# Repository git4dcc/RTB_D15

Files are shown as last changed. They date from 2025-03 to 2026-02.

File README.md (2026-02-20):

# RTB_D15




My Homebrew [D15](https://rtb4dcc.de/hardware/decoder/d15/) decoder is a drop in replacement for the original analog Minitrix (#11130) PCB. The decoder is designed to integrate into the [RTB](https://rtb4dcc.de/concept/) digital control infrastructure.

<details>
<summary>See also</summary>

- [RTB_D12 - custom](/../../../../git4dcc/RTB_D12) (Fleischmann V100)
- [RTB_D13 - custom](/../../../../git4dcc/RTB_D13) (Minitrix coach)
- [RTB_D16 - NEM651](/../../../../git4dcc/RTB_D16)
- [RTB_D20 - NEM651](/../../../../git4dcc/RTB_D20)
- [RTB_D21 - Next18](/../../../../git4dcc/RTB_D21)
- [RTB_D22 - Plux16](/../../../../git4dcc/RTB_D22)
- [RTB_D23 - NEM652](/../../../../git4dcc/RTB_D23)

</details>

<details>
<summary>User Guides</summary>

- User Guide - DE
- [User Guide - EN](https://rtb4dcc.de/rtb_decoder_reference_en/)

</details>

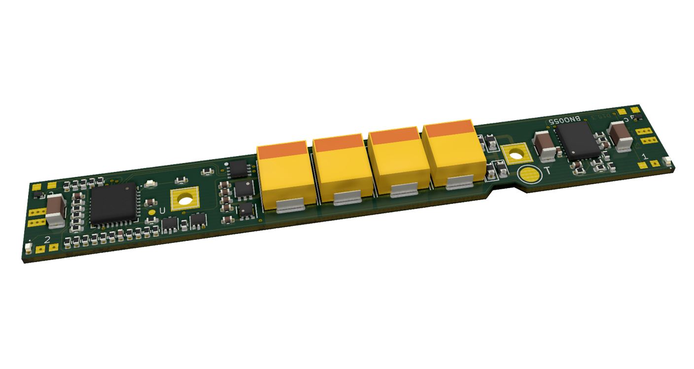
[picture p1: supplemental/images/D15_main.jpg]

<br>

## Decoder features
- **Minitirx V160** PCB decoder
- **DCC**
  - DCC-A automatic logon
  - DCC-R protocol extension
  - Service Mode Programming
- **Railcom**
  - Channel 1/2
  - POM, xPOM
  - DYN: Speed, QoS, Track-voltage, Motor-current, AUX-current, Temp, Distance travelled
- 7-18V track voltage
- heartbeat LED
- adjustable max motor current (default 250mA)
- adjustable max AUX current (default 250mA)
- over temp protection
- Function output: LF/LR (dimmable, 1.4kHz), LED on PCB
- Function output: AUX1/AUX2 (dimmable, 1.4kHz) for driver cabin (LEDs on PCB)
- Function output: AUX3/AUX4 logic level
- Function output: AUX5/AUX6 open drain (each 250mA)
- buffer capacitor 4x330uF
- optional 9-axis orientation sensor
- <10mA idle power consumption
- Firmware update over main tracks via DCC-R protocol

# Hardware
The current PCB layout uses SMD footprints with 0.5mm pitch and mainly 0402 parts. Reflow soldering is mandatory whereas handsoldering almost impossible.

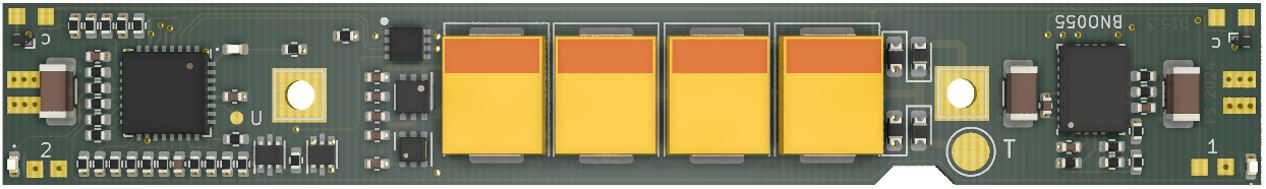
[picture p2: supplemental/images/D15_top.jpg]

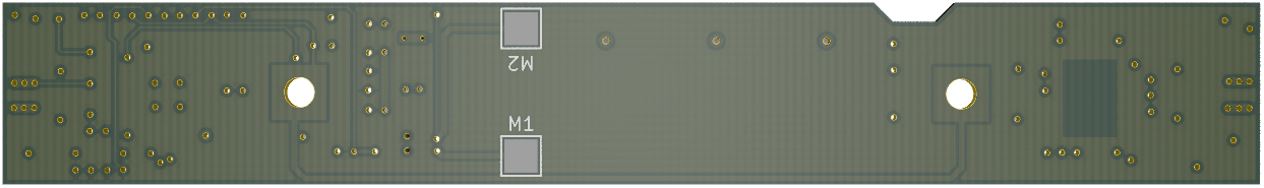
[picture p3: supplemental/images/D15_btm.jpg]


## PCB
- 4-layer PCB, FR4, 0.8mm
- CPU: AVR64DA32
- Motor bridge: DRV8231
- Inrush limiter: TPS22810
- 9-axis absolute-orientation sensor: BNO055

## Kicad
[Schematic](doc/D12_schematic.pdf) | [Layout](doc/D12_layout.pdf) | [Gerber](gerber)

<details>
<summary>Dependency</summary>
<br>

:yellow_circle: Requires my Kicad project library [RTB_SamacSys](https://github.com/git4dcc/RTB_SamacSys) in the same directory tree.

</details>

## Firmware
Filename structure: { **pcb** }{ **code** }{ **version** }.hex

Example: **D15F0001**.hex

| | Description |
| --- | --- |
| **pcb** | Name of matching hardware (**D12**) |
| **code** | Type of code contained (**R**=rom, **B**=bootloader, **F**=flash, **U**=bld update, **P**=UPDI factory code) |
| **version** | Release version (**####**) |

[Firmware files](firmware)

# Images
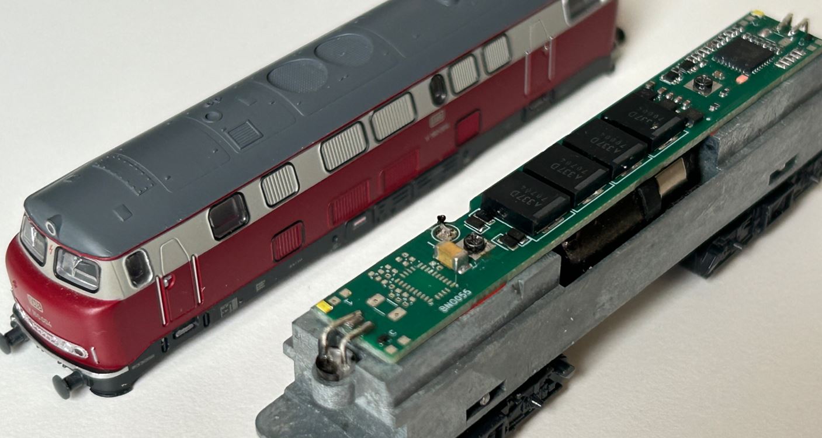
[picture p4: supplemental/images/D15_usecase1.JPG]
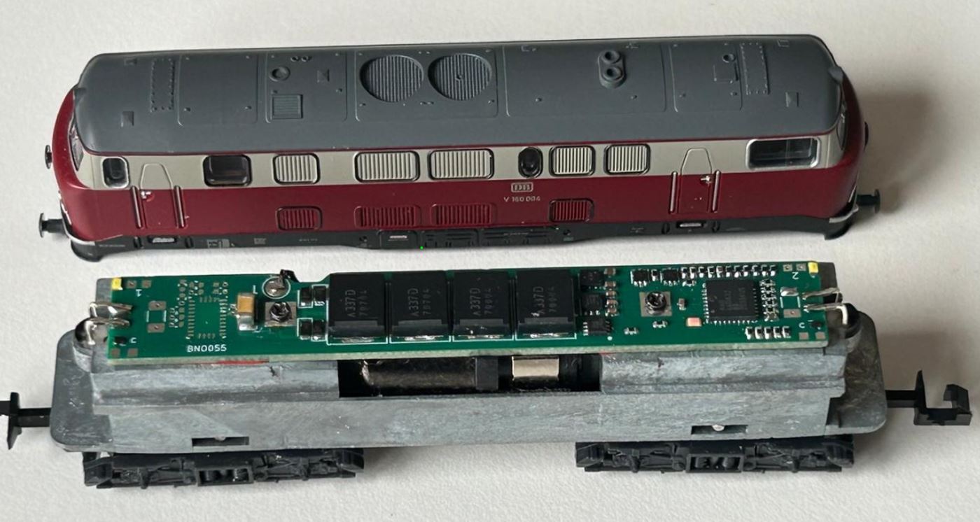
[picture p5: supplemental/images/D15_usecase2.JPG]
 

# YouTube
See the D15 decoder (rev 0) in action.<br><br>
[](https://youtu.be/xmjQG59Y9LQ)

This project is intended for hobby use only and is distributed in accordance with the Apache License 2.0 agreement.

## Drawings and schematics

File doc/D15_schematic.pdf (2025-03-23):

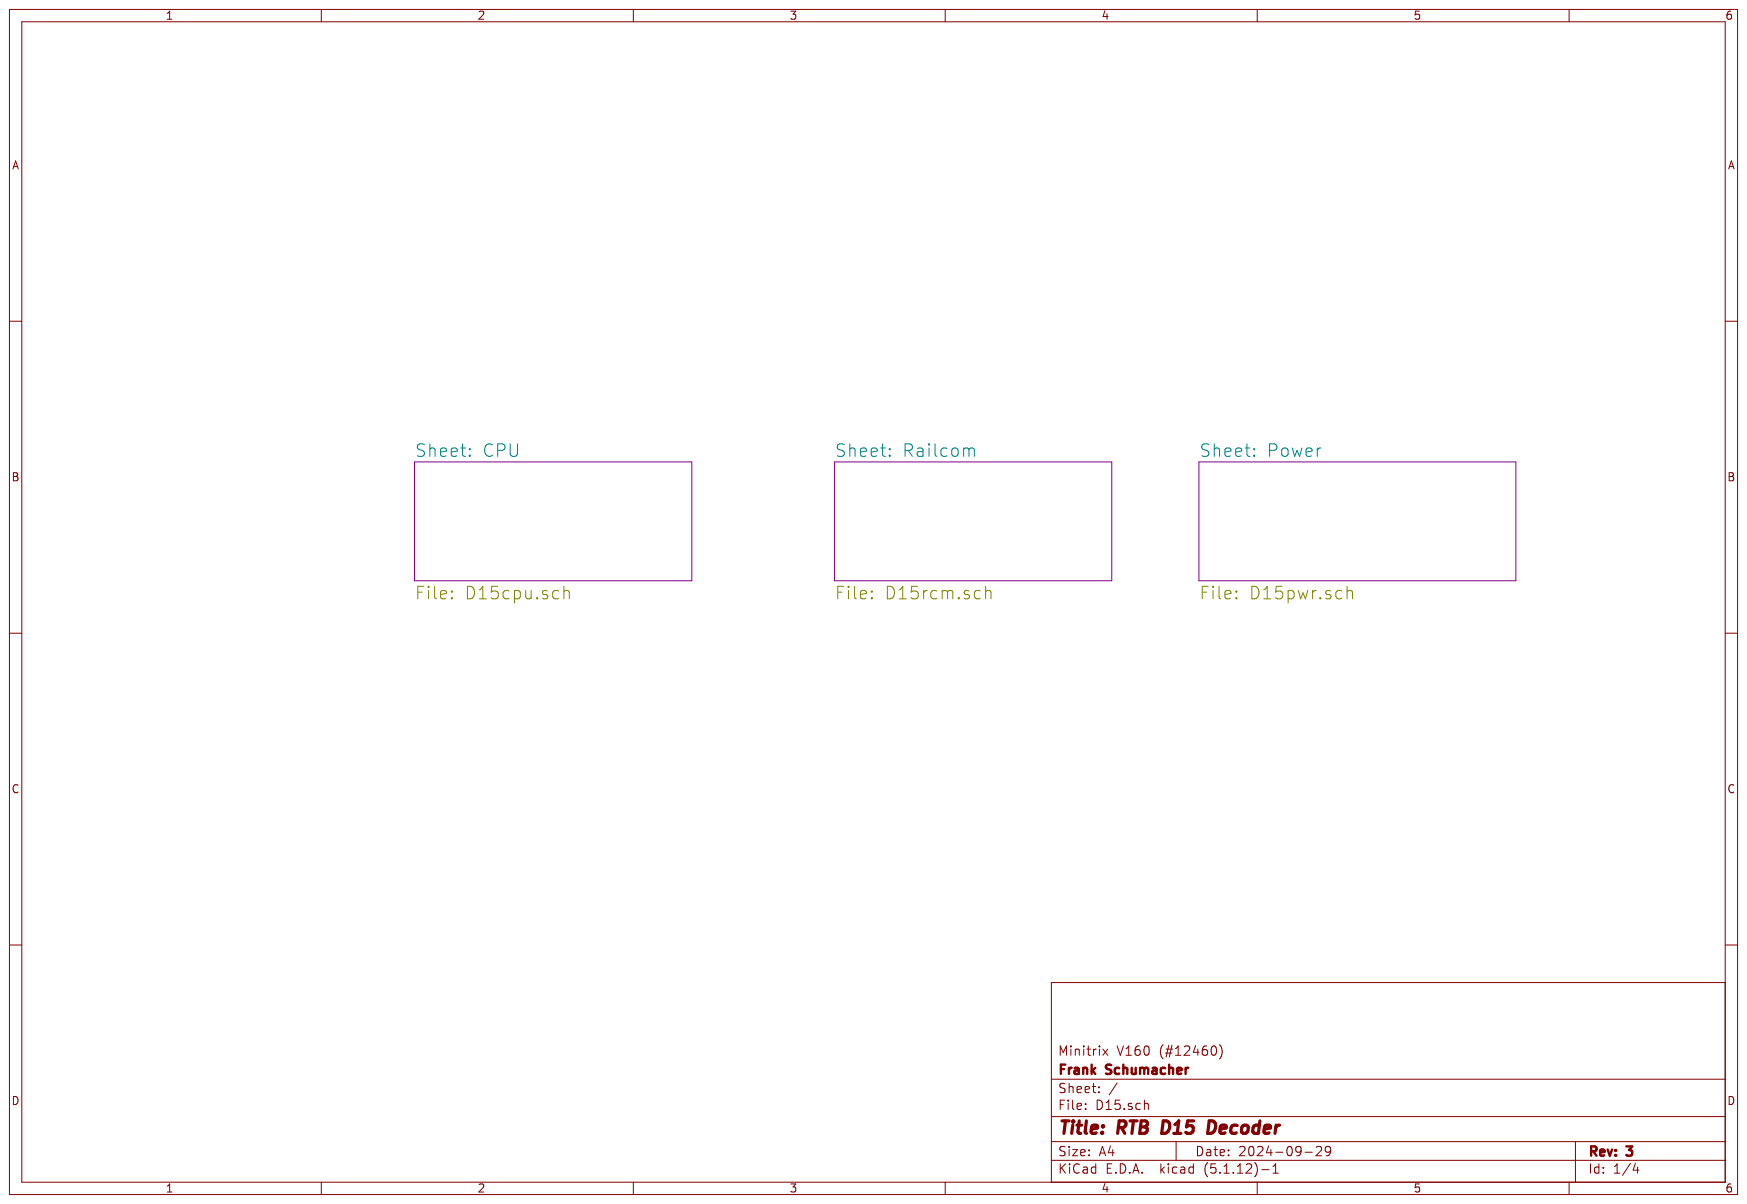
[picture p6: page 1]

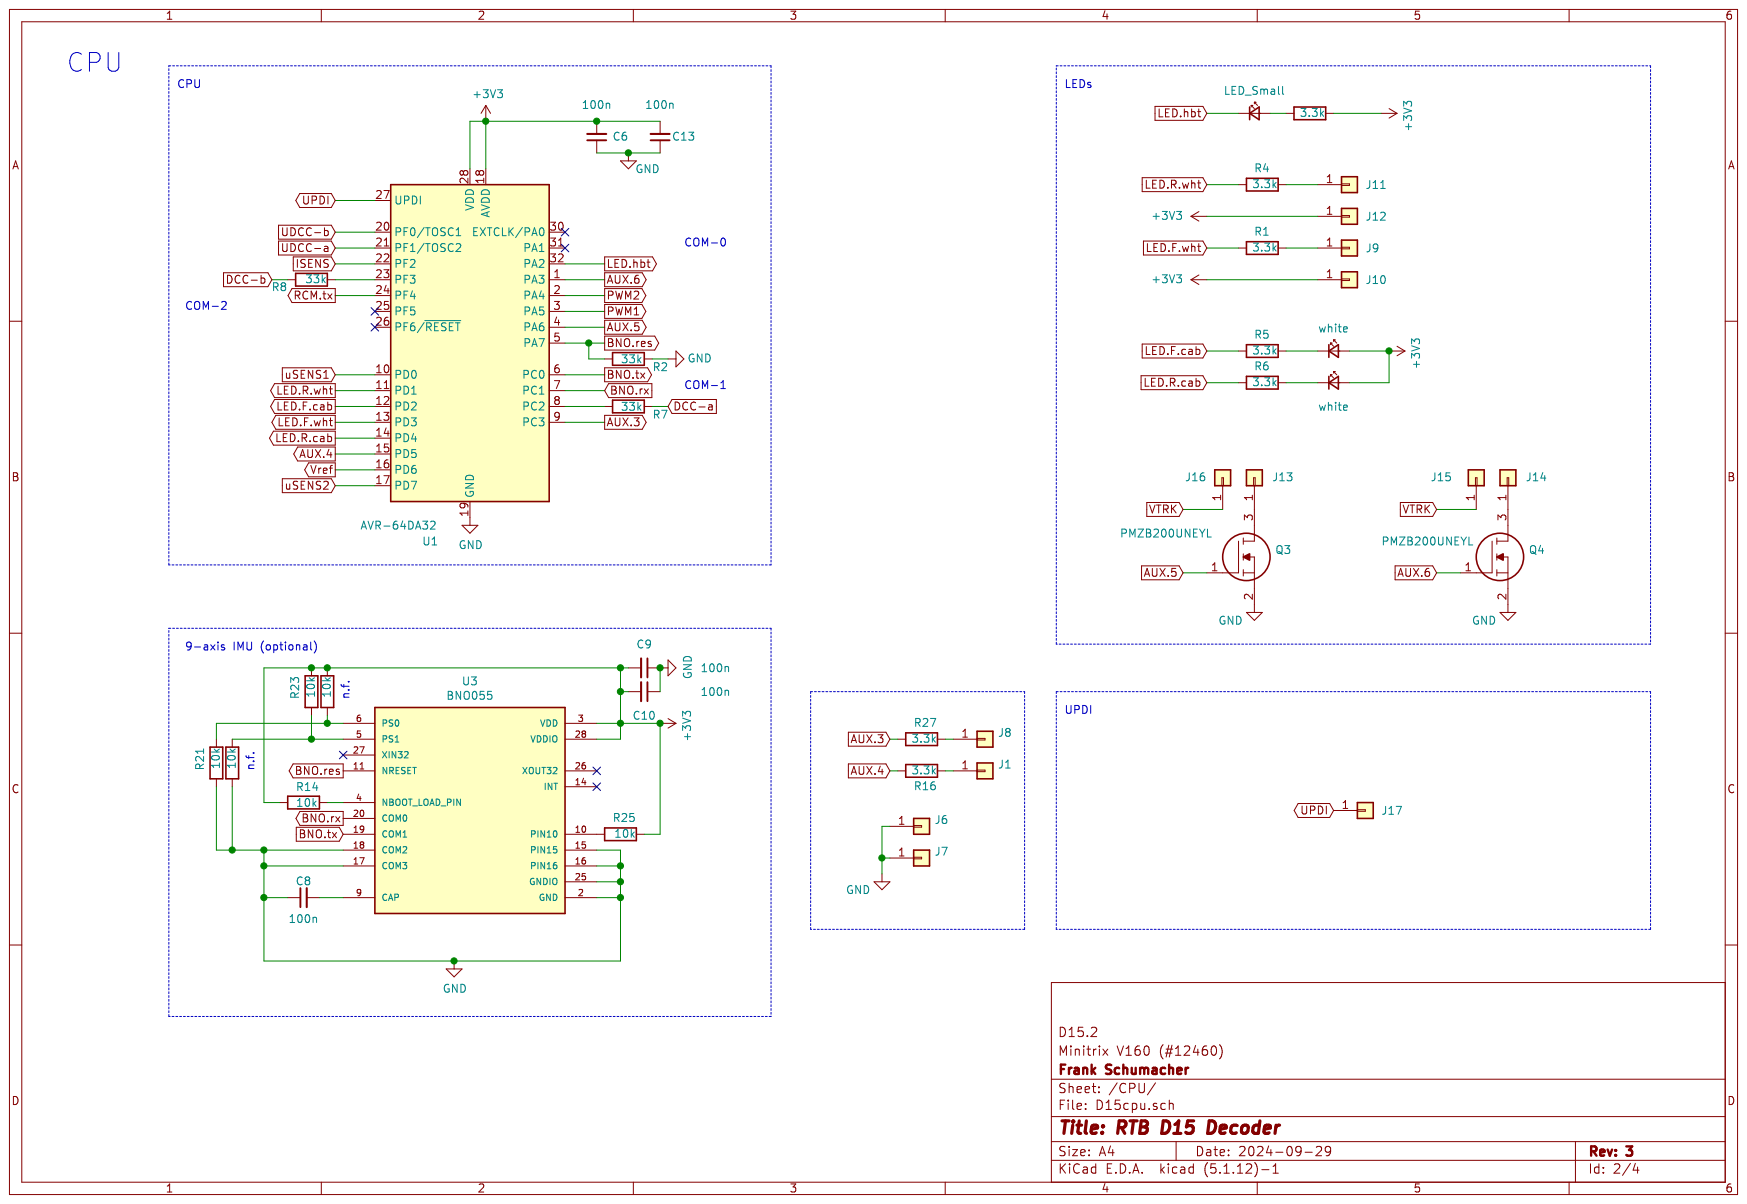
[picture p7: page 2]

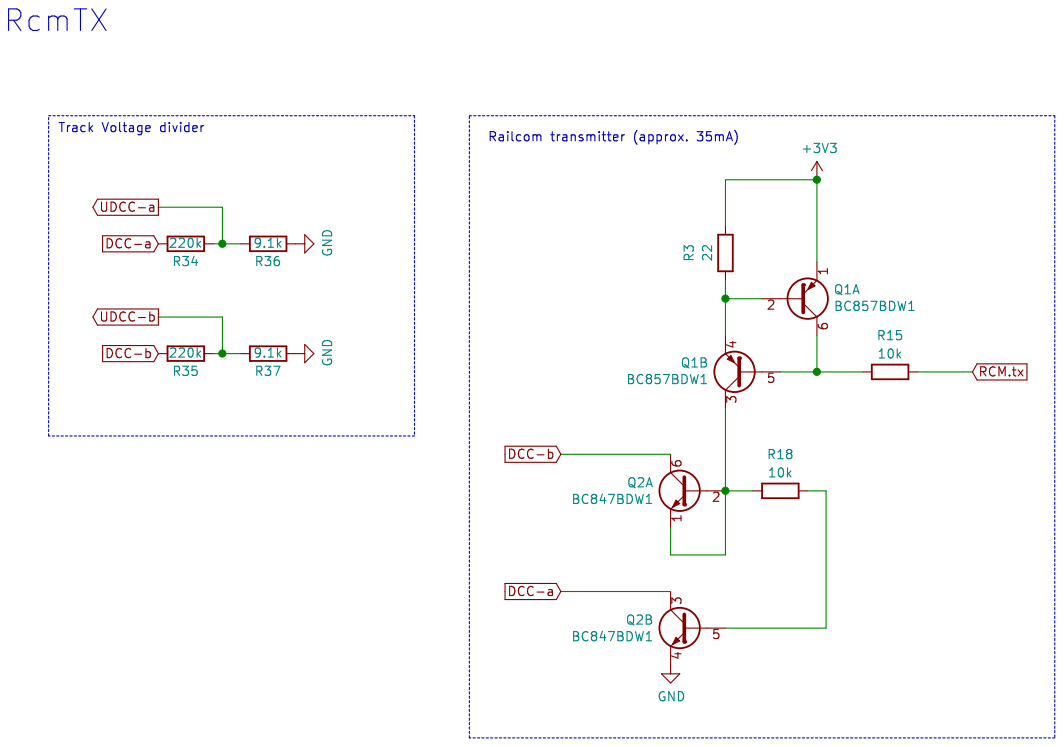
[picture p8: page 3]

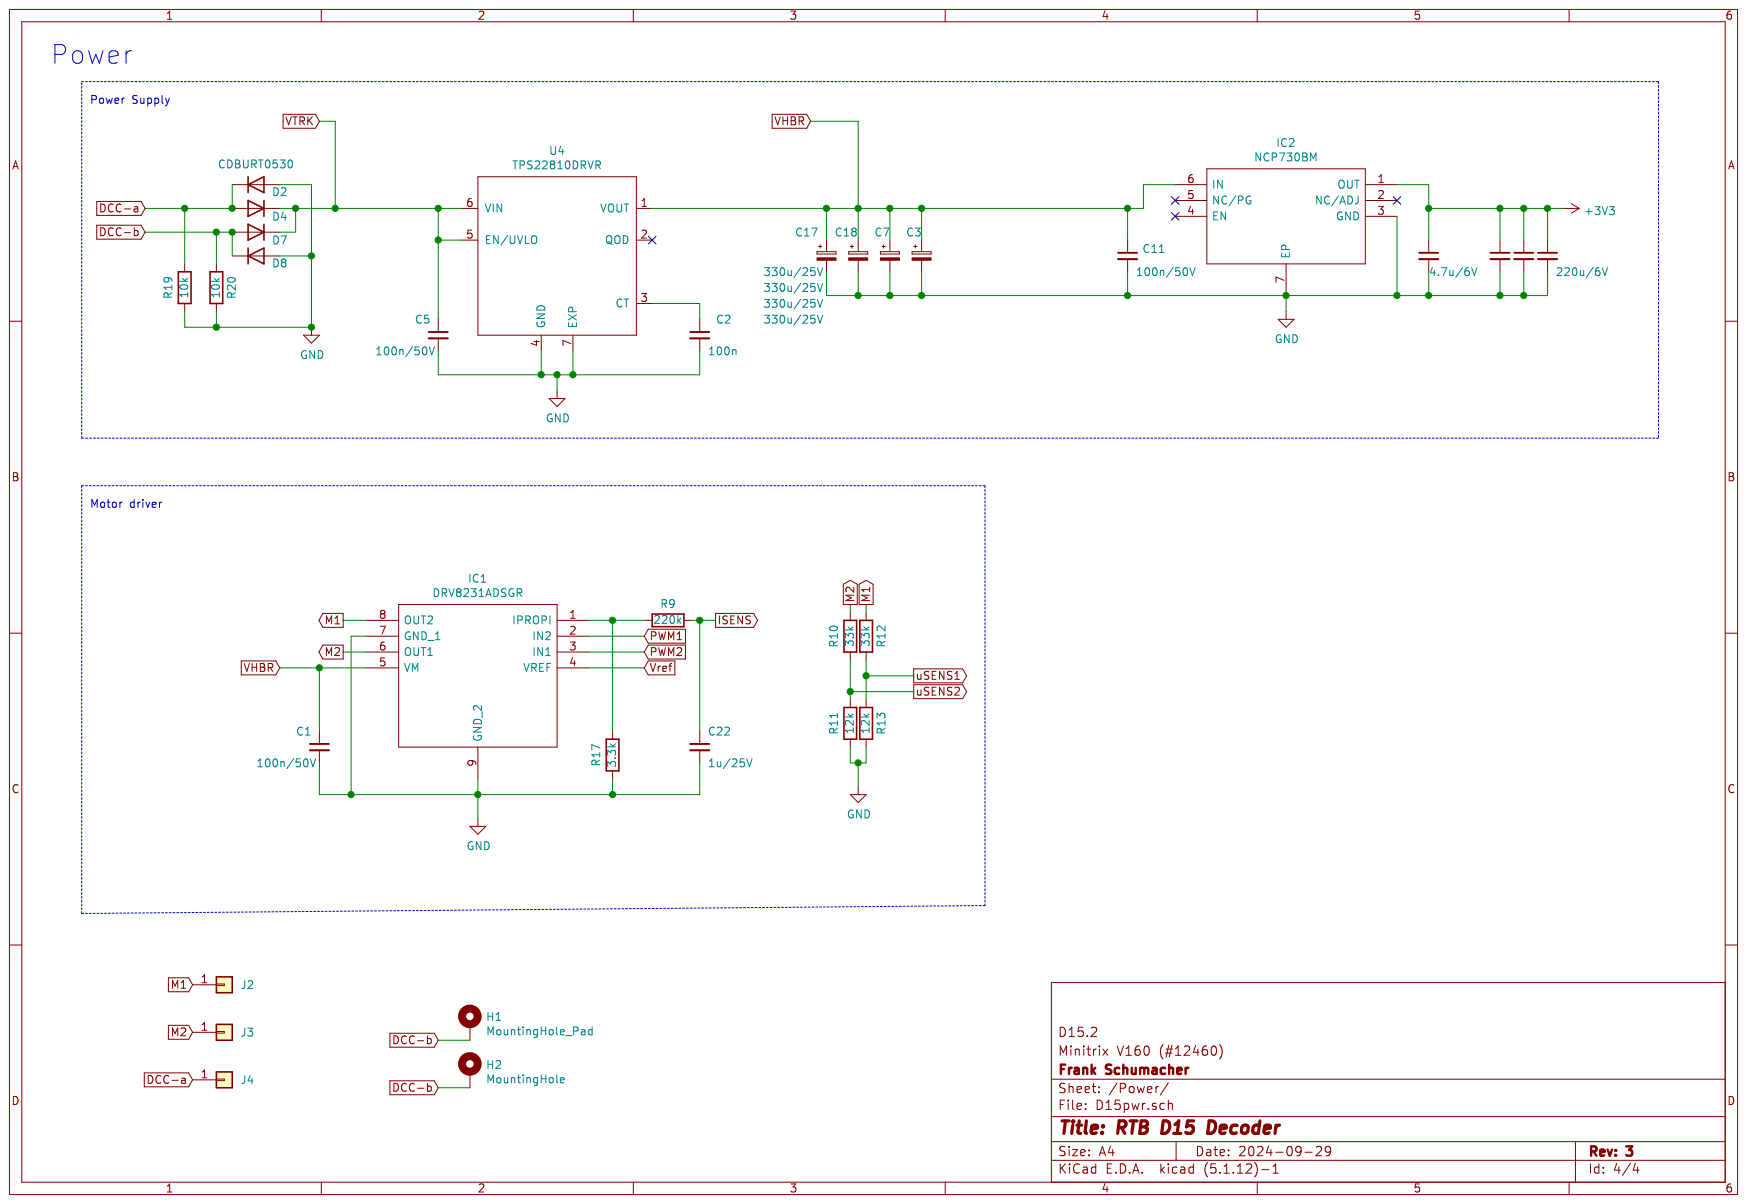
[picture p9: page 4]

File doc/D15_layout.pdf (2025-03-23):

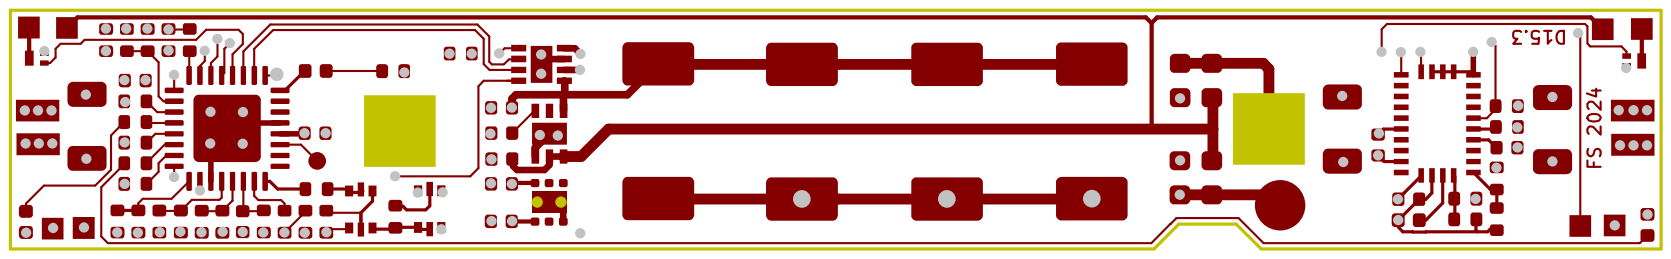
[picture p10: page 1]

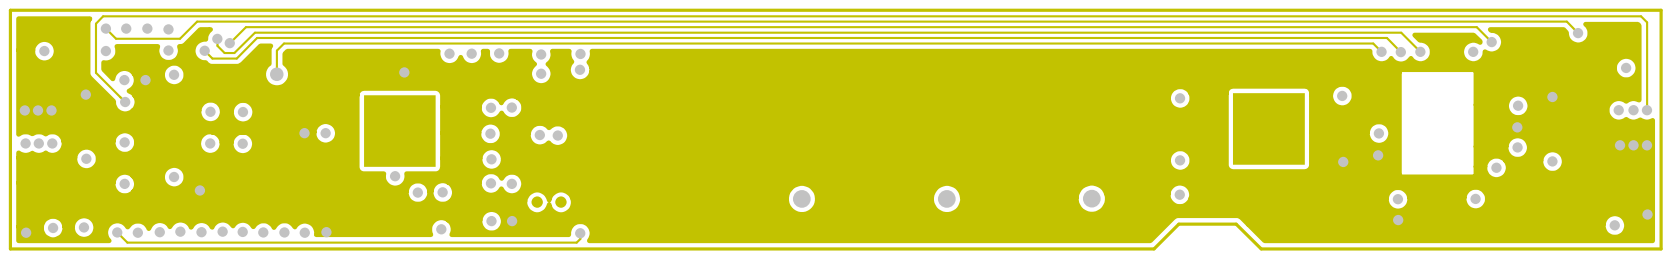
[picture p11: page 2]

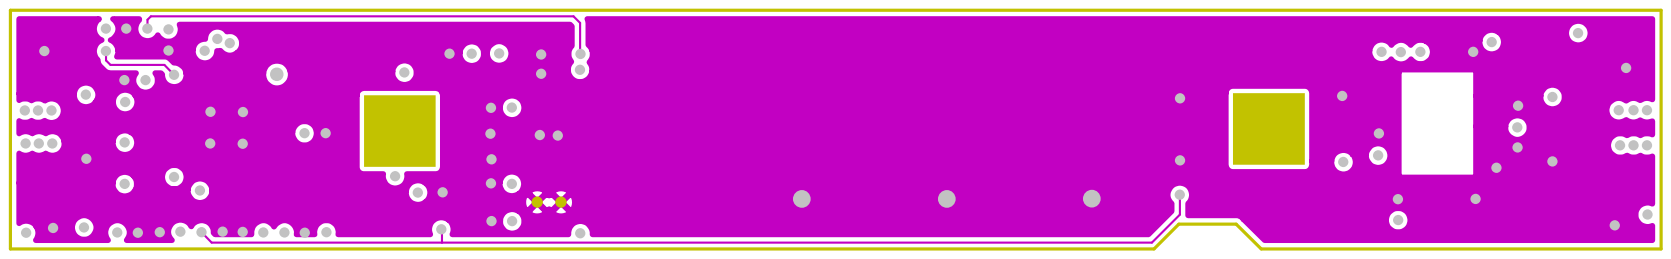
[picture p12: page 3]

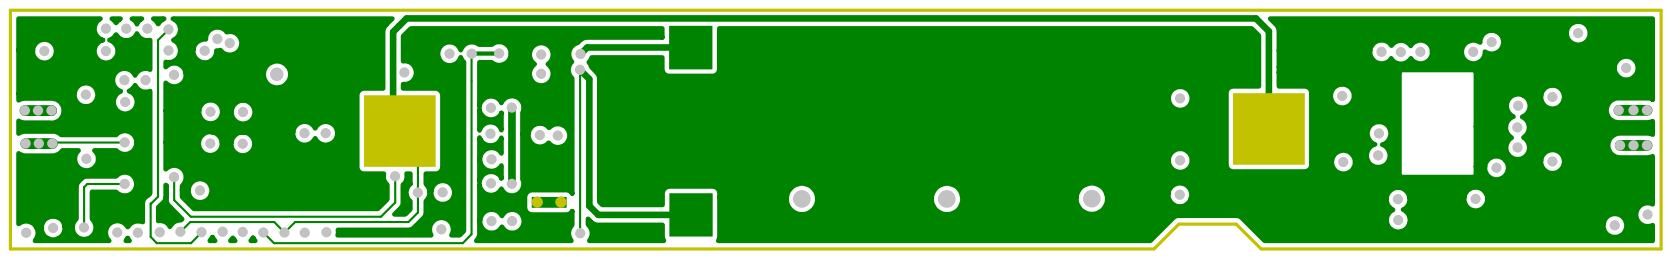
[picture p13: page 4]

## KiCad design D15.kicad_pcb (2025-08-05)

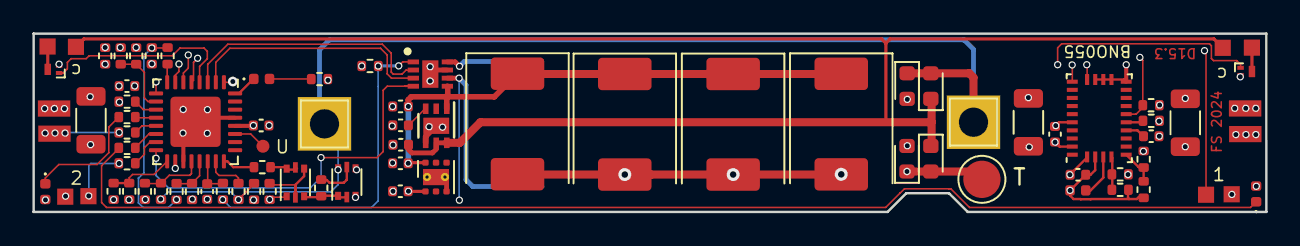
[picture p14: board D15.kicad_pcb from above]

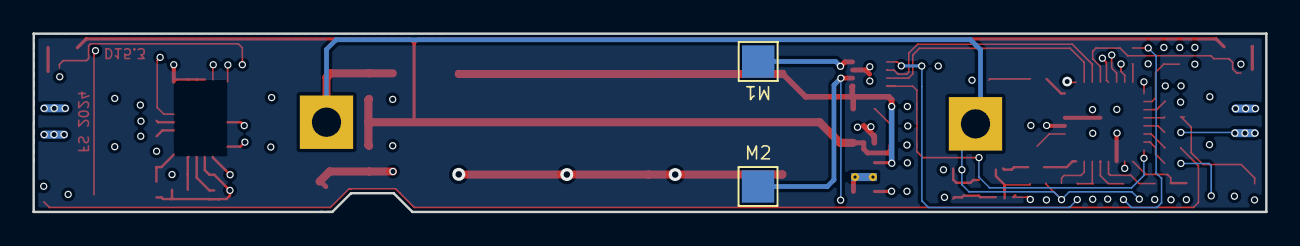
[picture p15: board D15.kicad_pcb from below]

Board: 4 copper layers, 76.0 x 11.0 mm, 83 parts (2 on the bottom side), 52 nets.

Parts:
C1, C5, C11: 100n/50V; C_0402_1005Metric
C2, C6, C8, C9, C10, C13: 100n; C_0402_1005Metric
C3, C7, C17, C18: 330u/25V; CP_EIA-7361-38_AVX-V
C4, C14, C15: 220u/6V; C_1206_3216Metric
C12: 4.7u/6V; C_0402_1005Metric
C22: 1u/25V; C_0402_1005Metric
D1, D5: white; LED_0402_1005Metric
D2, D4, D7, D8: CDBURT0530; D_0603_1608Metric
D3: LED_Small; LED_0402_1005Metric
H1: MountingHole_Pad; TestPoint_THTPad_2.5x2.5mm_Drill1.2mm
H2: MountingHole; TestPoint_THTPad_2.5x2.5mm_Drill1.2mm
IC1: DRV8231ADSGR; SON50P200X200X80-9N
IC2: NCP730BM; WSON-6-1EP_2x2mm_P0.65mm_EP1x1.6mm_ThermalVias
J1, J6, J7, J8, J9, J10, J11, J12, J13, J14, J15, J16, J17: Conn_01x01; DummyNet-Connector
J2, J3: Conn_01x01; TestPoint_THTPad_2.0x2.0mm_Drill1.0mm
J4: Conn_01x01; TestPoint_Pad_D2.5mm
Q1: BC857BDW1; SOT-666
Q2: BC847BDW1; SOT-666
Q3, Q4: PMZB200UNEYL; Diodes_DFN1006-3
R1, R4, R5, R6, R16, R26, R27: 3.3k; R_0402_1005Metric
R2, R7, R8, R10, R12: 33k; R_0402_1005Metric
R3: 22; R_0402_1005Metric
R9, R34, R35: 220k; R_0402_1005Metric
R11, R13: 12k; R_0402_1005Metric
R14, R15, R18, R19, R20, R21, R22, R23, R24, R25: 10k; R_0402_1005Metric
R17: 1k; R_0402_1005Metric
R36, R37: 9.1k; R_0402_1005Metric
U1: AVR-64DA32; VQFN-32-1EP_5x5mm_P0.5mm_EP3.1x3.1mm
U3: BNO055; LGA-28_5.2x3.8mm_P0.5mm
U4: TPS22810DRVR; DFN-6-1EP_2x2mm_P0.65mm_EP1x1.6mm

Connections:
+3V3: C4.1, C6.2, C9.2, C10.2, C12.1, C13.2, C14.1, C15.1, D1.2, D5.2, IC2.1, J10.1, J12.1, Q1.1, R3.1, R14.2, R23.2, R24.2, R25.2, R26.2, U1.18, U1.28, U3.3, U3.28
AUX.3: R27.1, U1.9
AUX.4: R16.1, U1.15
AUX.5: Q3.1, U1.4
AUX.6: Q4.1, U1.1
BNO.res: R2.2, U1.5, U3.11
BNO.rx: U1.7, U3.20
BNO.tx: U1.6, U3.19
DCC-a: D2.1, D4.2, J4.1, Q2.3, R7.1, R19.2, R34.1
DCC-b: D7.2, D8.1, H1.1, H2.1, Q2.6, R8.1, R20.2, R35.1
GND: C1.2, C2.2, C3.2, C4.2, C5.2, C6.1, C7.2, C8.1, C9.1, C10.1, C11.2, C12.2, C13.1, C14.2, C15.2, C17.2, C18.2, C22.2, D2.2, D8.2, IC1.7, IC1.9, IC2.3, IC2.7, J6.1, J7.1, Q2.4, Q3.2, Q4.2, R2.1, R11.1, R13.1, R17.1, R19.1, R20.1, R21.1, R22.1, R36.2, R37.2, U1.19, U1.29, U1.33, U3.2, U3.15, U3.16, U3.17, U3.18, U3.25, U4.4, U4.7
ISENS: C22.1, R9.2, U1.22
LED.F.cab: R5.1, U1.12
LED.F.wht: R1.1, U1.13
LED.R.cab: R6.1, U1.14
LED.R.wht: R4.1, U1.11
LED.hbt: D3.1, U1.32
M1: IC1.8, J2.1, R12.2
M2: IC1.6, J3.1, R10.2
unnamed: C2.1, U4.3
unnamed: C8.2, U3.9
unnamed: D1.1, R5.2
unnamed: D3.2, R26.1
unnamed: D5.1, R6.2
unnamed: IC1.1, R9.1, R17.2
unnamed: J1.1, R16.2
unnamed: J8.1, R27.2
unnamed: J9.1, R1.2
unnamed: J11.1, R4.2
unnamed: J13.1, Q3.3
unnamed: J14.1, Q4.3
unnamed: Q1.2, Q1.4, R3.2
unnamed: Q1.3, Q2.1, Q2.2, R18.2
unnamed: Q1.5, Q1.6, R15.2
unnamed: Q2.5, R18.1
unnamed: R7.2, U1.8
unnamed: R8.2, U1.23
unnamed: R14.1, U3.4
unnamed: R21.2, R24.1, U3.6
unnamed: R22.2, R23.1, U3.5
unnamed: R25.1, U3.10
PWM1: IC1.2, U1.3
PWM2: IC1.3, U1.2
RCM.tx: R15.1, U1.24
UDCC-a: R34.2, R36.1, U1.21
UDCC-b: R35.2, R37.1, U1.20
UPDI: J17.1, U1.27
VHBR: C1.1, C3.1, C7.1, C11.1, C17.1, C18.1, IC1.5, IC2.6, U4.1
VTRK: C5.1, D4.1, D7.1, J15.1, J16.1, U4.5, U4.6
Vref: IC1.4, U1.16
uSENS1: R12.1, R13.2, U1.10
uSENS2: R10.1, R11.2, U1.17

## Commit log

2024-09-29 Changed H-Bridge, added hardware PWM
    [D15.kicad_pcb, D15.sch, D15cpu.sch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]
2025-03-23 add: decoder lock
    [D15.kicad_pcb, D15.sch, D15cpu.sch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]
2025-08-05 mod: led automation
    [D15.kicad_pcb, D15pwr.sch]
